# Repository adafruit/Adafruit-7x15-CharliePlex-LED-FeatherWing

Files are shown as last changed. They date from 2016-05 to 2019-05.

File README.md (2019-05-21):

## Adafruit 7x15 CharliePlex LED FeatherWings PCB
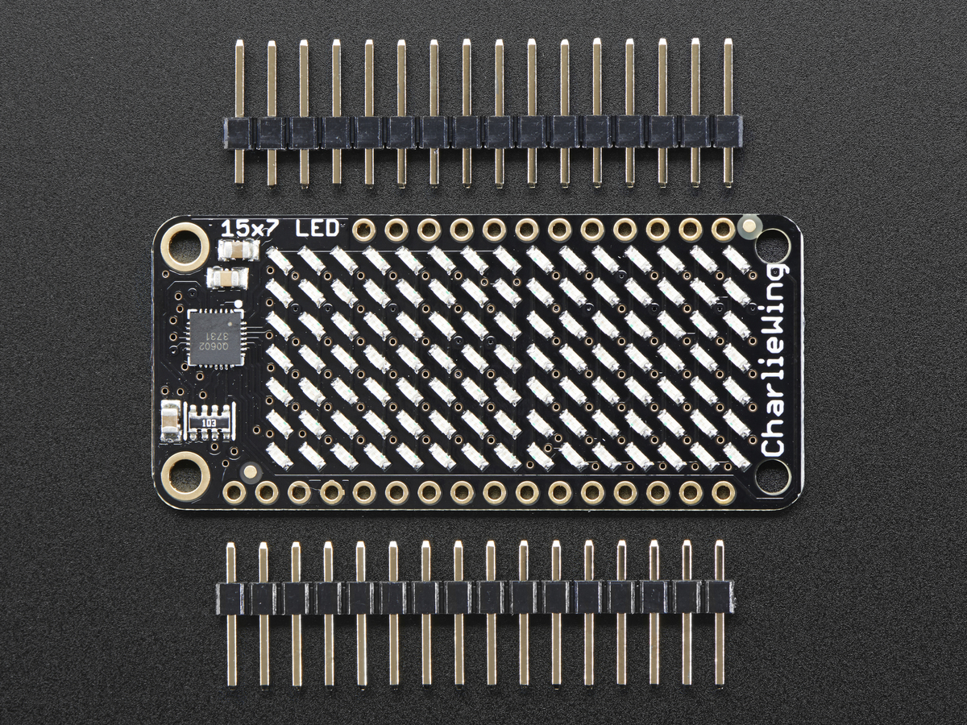
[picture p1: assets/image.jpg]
<a href="http://www.adafruit.com/products/3134"><br/>
Click here to purchase one from the Adafruit shop</a>

You wont be able to look away from the mesmerizing patterns created by this Adafruit 15x7 CharliePlex LED Matrix Display FeatherWing.  This 15x7 LED display can be paired with any of our Feather boards for a beautiful, bright grid of 105 charlieplexed LEDs. It even comes with a built-in charlieplex driver that is run over I2C.

We carry these FeatherWings in five vivid colors!

What is particularly nice about this Wing is the I2C LED driver chip has the ability to PWM each individual LED in a 15x7 grid so you can have beautiful LED lighting effects, without a lot of pin twiddling. Simply tell the chip which LED on the grid you want lit, and what brightness and it's all taken care of for you. You get 8-bit (256 level) dimming for each individual LED.

PCB files for 7x15 CharliePlex LED FeatherWings. The format is EagleCAD schematic and board layout

For more details, check out the product pages at

   * https://www.adafruit.com/product/3134
   * https://www.adafruit.com/product/3135
   * https://www.adafruit.com/product/3136
   * https://www.adafruit.com/product/3137
   * https://www.adafruit.com/product/3138

### License

Adafruit invests time and resources providing this open source design, please support Adafruit and open-source hardware by purchasing products from [Adafruit](https://www.adafruit.com)!

All text above must be included in any redistribution

Designed by Limor Fried/Ladyada for Adafruit Industries.
Creative Commons Attribution/Share-Alike, all text above must be included in any redistribution. 
See license.txt for additional information.

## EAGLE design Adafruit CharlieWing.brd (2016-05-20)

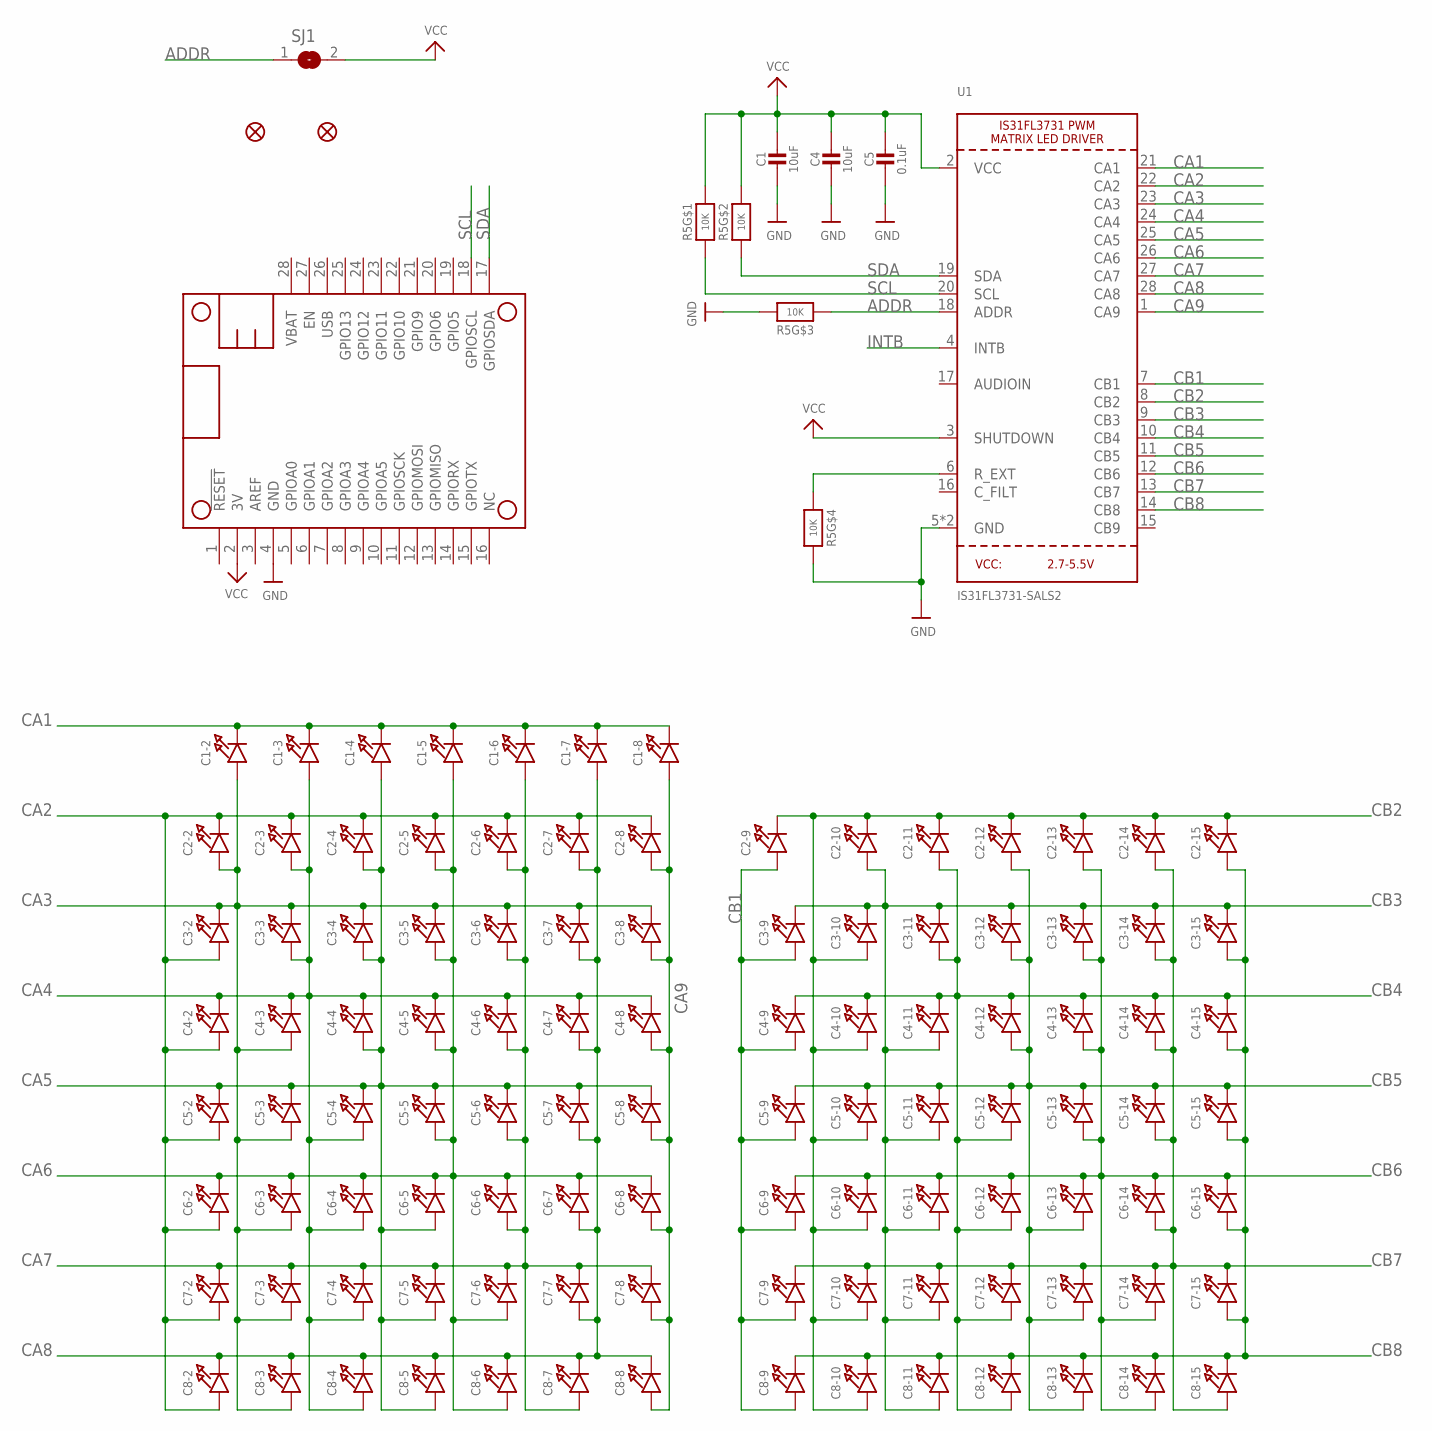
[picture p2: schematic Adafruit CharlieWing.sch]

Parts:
C1, C4: 10uF; 0805-NO
C1-2, C1-3, C1-4, C1-5, C1-6, C1-7, C1-8, C2-2, C2-3, C2-4, C2-5, C2-6, C2-7, C2-8, C2-9, C2-10, C2-11, C2-12, C2-13, C2-14, C2-15, C3-2, C3-3, C3-4, C3-5, C3-6, C3-7, C3-8, C3-9, C3-10, C3-11, C3-12, C3-13, C3-14, C3-15, C4-2, C4-3, C4-4, C4-5, C4-6, C4-7, C4-8, C4-9, C4-10, C4-11, C4-12, C4-13, C4-14, C4-15, C5-2, C5-3, C5-4, C5-5, C5-6, C5-7, C5-8, C5-9, C5-10, C5-11, C5-12, C5-13, C5-14, C5-15, C6-2, C6-3, C6-4, C6-5, C6-6, C6-7, C6-8, C6-9, C6-10, C6-11, C6-12, C6-13, C6-14, C6-15, C7-2, C7-3, C7-4, C7-5, C7-6, C7-7, C7-8, C7-9, C7-10, C7-11, C7-12, C7-13, C7-14, C7-15, C8-2, C8-3, C8-4, C8-5, C8-6, C8-7, C8-8, C8-9, C8-10, C8-11, C8-12, C8-13, C8-14, C8-15: LED0603_NOOUTLINE; CHIPLED_0603_NOOUTLINE
C5: 0.1uF; 0805-NO
FID1, FID2: FIDUCIAL""; FIDUCIAL_1MM
MS1: FEATHERWING
R5: 10K; RESPACK_4X0603
SJ1: SOLDERJUMPER; SOLDERJUMPER_ARROW_NOPASTE
U1: IS31FL3731-SALS2; QFN28_4MM_0.4MM

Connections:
ADDR: R5.3 (1), SJ1.1, U1.18 (ADDR)
CA1: C1-2.C, C1-3.C, C1-4.C, C1-5.C, C1-6.C, C1-7.C, C1-8.C, U1.21 (CA1)
CA2: C2-2.C, C2-3.C, C2-4.C, C2-5.C, C2-6.C, C2-7.C, C2-8.C, C3-2.A, C4-2.A, C5-2.A, C6-2.A, C7-2.A, C8-2.A, U1.22 (CA2)
CA3: C1-2.A, C2-2.A, C3-2.C, C3-3.C, C3-4.C, C3-5.C, C3-6.C, C3-7.C, C3-8.C, C4-3.A, C5-3.A, C6-3.A, C7-3.A, C8-3.A, U1.23 (CA3)
CA4: C1-3.A, C2-3.A, C3-3.A, C4-2.C, C4-3.C, C4-4.C, C4-5.C, C4-6.C, C4-7.C, C4-8.C, C5-4.A, C6-4.A, C7-4.A, C8-4.A, U1.24 (CA4)
CA5: C1-4.A, C2-4.A, C3-4.A, C4-4.A, C5-2.C, C5-3.C, C5-4.C, C5-5.C, C5-6.C, C5-7.C, C5-8.C, C6-5.A, C7-5.A, C8-5.A, U1.25 (CA5)
CA6: C1-5.A, C2-5.A, C3-5.A, C4-5.A, C5-5.A, C6-2.C, C6-3.C, C6-4.C, C6-5.C, C6-6.C, C6-7.C, C6-8.C, C7-6.A, C8-6.A, U1.26 (CA6)
CA7: C1-6.A, C2-6.A, C3-6.A, C4-6.A, C5-6.A, C6-6.A, C7-2.C, C7-3.C, C7-4.C, C7-5.C, C7-6.C, C7-7.C, C7-8.C, C8-7.A, U1.27 (CA7)
CA8: C1-7.A, C2-7.A, C3-7.A, C4-7.A, C5-7.A, C6-7.A, C7-7.A, C8-2.C, C8-3.C, C8-4.C, C8-5.C, C8-6.C, C8-7.C, C8-8.C, U1.28 (CA8)
CA9: C1-8.A, C2-8.A, C3-8.A, C4-8.A, C5-8.A, C6-8.A, C7-8.A, C8-8.A, U1.1 (CA9)
CB1: C2-9.A, C3-9.A, C4-9.A, C5-9.A, C6-9.A, C7-9.A, C8-9.A, U1.7 (CB1)
CB2: C2-9.C, C2-10.C, C2-11.C, C2-12.C, C2-13.C, C2-14.C, C2-15.C, C3-10.A, C4-10.A, C5-10.A, C6-10.A, C7-10.A, C8-10.A, U1.8 (CB2)
CB3: C2-10.A, C3-9.C, C3-10.C, C3-11.C, C3-12.C, C3-13.C, C3-14.C, C3-15.C, C4-11.A, C5-11.A, C6-11.A, C7-11.A, C8-11.A, U1.9 (CB3)
CB4: C2-11.A, C3-11.A, C4-9.C, C4-10.C, C4-11.C, C4-12.C, C4-13.C, C4-14.C, C4-15.C, C5-12.A, C6-12.A, C7-12.A, C8-12.A, U1.10 (CB4)
CB5: C2-12.A, C3-12.A, C4-12.A, C5-9.C, C5-10.C, C5-11.C, C5-12.C, C5-13.C, C5-14.C, C5-15.C, C6-13.A, C7-13.A, C8-13.A, U1.11 (CB5)
CB6: C2-13.A, C3-13.A, C4-13.A, C5-13.A, C6-9.C, C6-10.C, C6-11.C, C6-12.C, C6-13.C, C6-14.C, C6-15.C, C7-14.A, C8-14.A, U1.12 (CB6)
CB7: C2-14.A, C3-14.A, C4-14.A, C5-14.A, C6-14.A, C7-9.C, C7-10.C, C7-11.C, C7-12.C, C7-13.C, C7-14.C, C7-15.C, C8-15.A, U1.13 (CB7)
CB8: C2-15.A, C3-15.A, C4-15.A, C5-15.A, C6-15.A, C7-15.A, C8-9.C, C8-10.C, C8-11.C, C8-12.C, C8-13.C, C8-14.C, C8-15.C, U1.14 (CB8)
GND: C1.2, C4.2, C5.2, MS1.4 (GND), R5.5 (2), R5.6 (2), U1.5 (GND), U1.THERMAL (GND)
INTB: U1.4 (INTB)
R_EXT: R5.4 (1), U1.6 (R_EXT)
SCL: MS1.18 (GPIOSCL), R5.1, U1.20 (SCL)
SDA: MS1.17 (GPIOSDA), R5.2 (1), U1.19 (SDA)
VCC: C1.1, C4.1, C5.1, MS1.2 (3V), R5.7 (2), R5.8 (2), SJ1.2, U1.2 (VCC), U1.3 (SHUTDOWN)

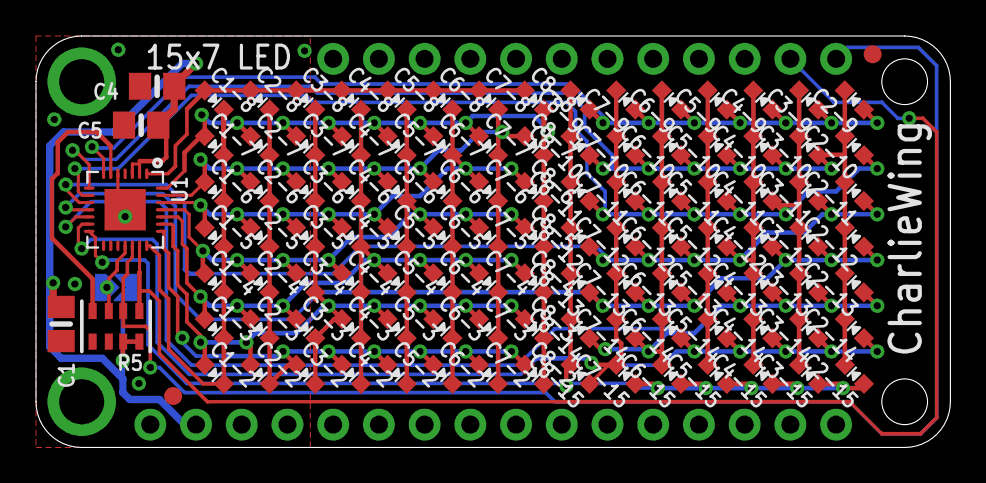
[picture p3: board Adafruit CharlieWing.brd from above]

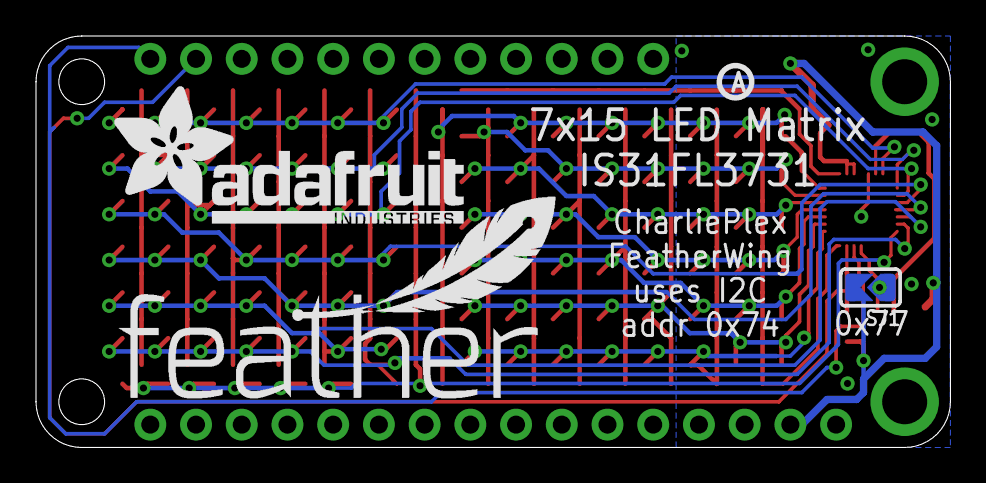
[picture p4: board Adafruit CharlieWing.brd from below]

Board: 2 copper layers, 50.8 x 22.9 mm, 117 parts (4 on the bottom side), 23 nets.

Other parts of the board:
U$1: PCBFEAT-REV-040
U$2: ADAFRUIT_TEXT_20MM
U$6: FEATHERLOGO

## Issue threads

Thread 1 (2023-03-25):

Make CharliePlex devices silent

jjdeprisco, 2023-03-25:
See my post here where I cover this topic:

https://forums.adafruit.com/viewtopic.php?t=199662

The noise is super annoying for those of us with acute hearing, and those who work in audio environments. If you are in a room with lots of background noise, you may not notice this, but it's very noticeable otherwise. Imagine if you have a device that uses multiple units...

I can't recall any of my other Arduino/Teensy/Particle type projects having issues like this. The CharliePlex Featherwing noise is particularly pronounced.

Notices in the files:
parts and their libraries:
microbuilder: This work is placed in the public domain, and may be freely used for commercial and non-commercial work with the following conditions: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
